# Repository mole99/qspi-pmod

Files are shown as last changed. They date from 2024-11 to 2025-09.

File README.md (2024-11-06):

# QSPI Pmod

A QSPI Pmod board designed in KiCad with one SPI Flash and two PSRAMs.

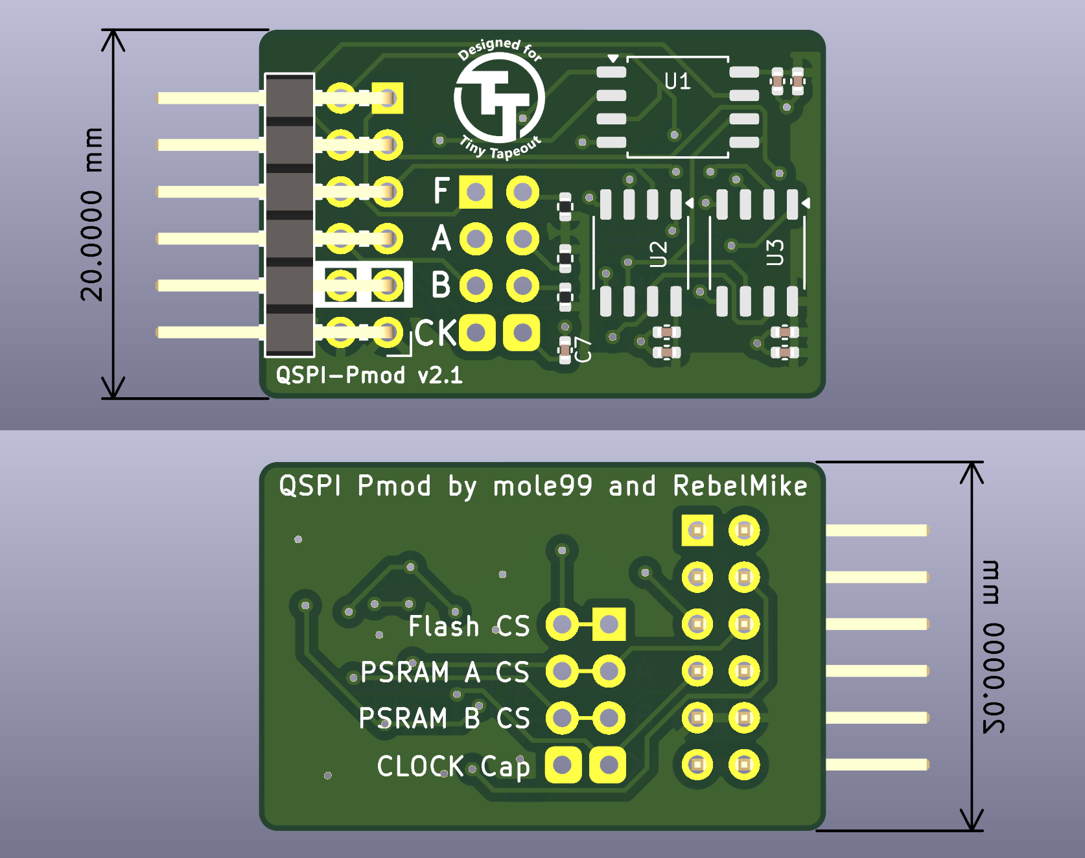
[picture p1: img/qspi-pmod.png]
PCB


# Pinout

| Pmod  | TinyTapeout | Function | Note |
|---|---|---|---|
| PMOD1 | uio[0] | CS0 (Flash) | Cut trace to disable (see below) |
| PMOD2 | uio[1] | SD0/MOSI | |
| PMOD3 | uio[2] | SD1/MISO | |
| PMOD4 | uio[3] | SCK | Short `CK` ("CLOCK cap") pin pair for delay by 22pF cap |
| PMOD5 | uio[4] | SD2 | |
| PMOD6 | uio[5] | SD3 | |
| PMOD7 | uio[6] | CS1 (RAM A) | Cut trace to disable (see below) |
| PMOD8 | uio[7] | CS2 (RAM B) | Cut trace to disable (see below) |

> [!NOTE]
> On the bottom side of the PCB, you can cut the traces for any of the 3 CS pins to disable its respective memory IC. When cut, a 1k resistor pulls up the chip's `/CS` to disable it. In this case, the respective pin could be used (via header thru-hole on the other side of the cut) as either an input or output.

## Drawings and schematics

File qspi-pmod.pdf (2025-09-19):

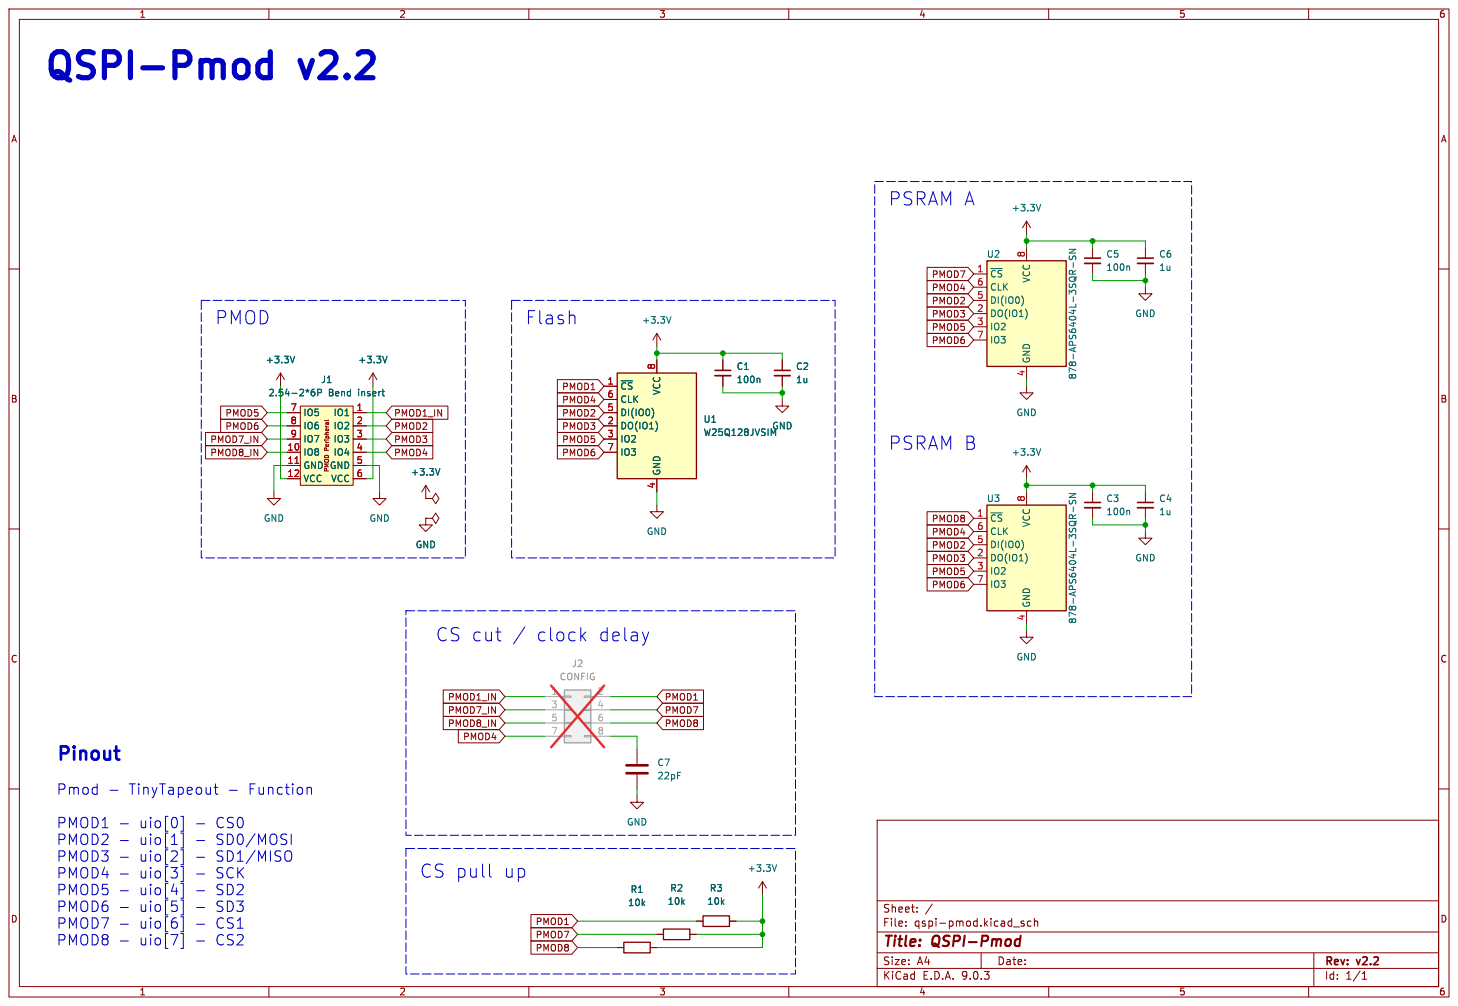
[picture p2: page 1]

CS cut / clock delay

File: qspi-pmod.kicad_sch Sheet: / R3

Id: 1/1 Title: QSPI-Pmod

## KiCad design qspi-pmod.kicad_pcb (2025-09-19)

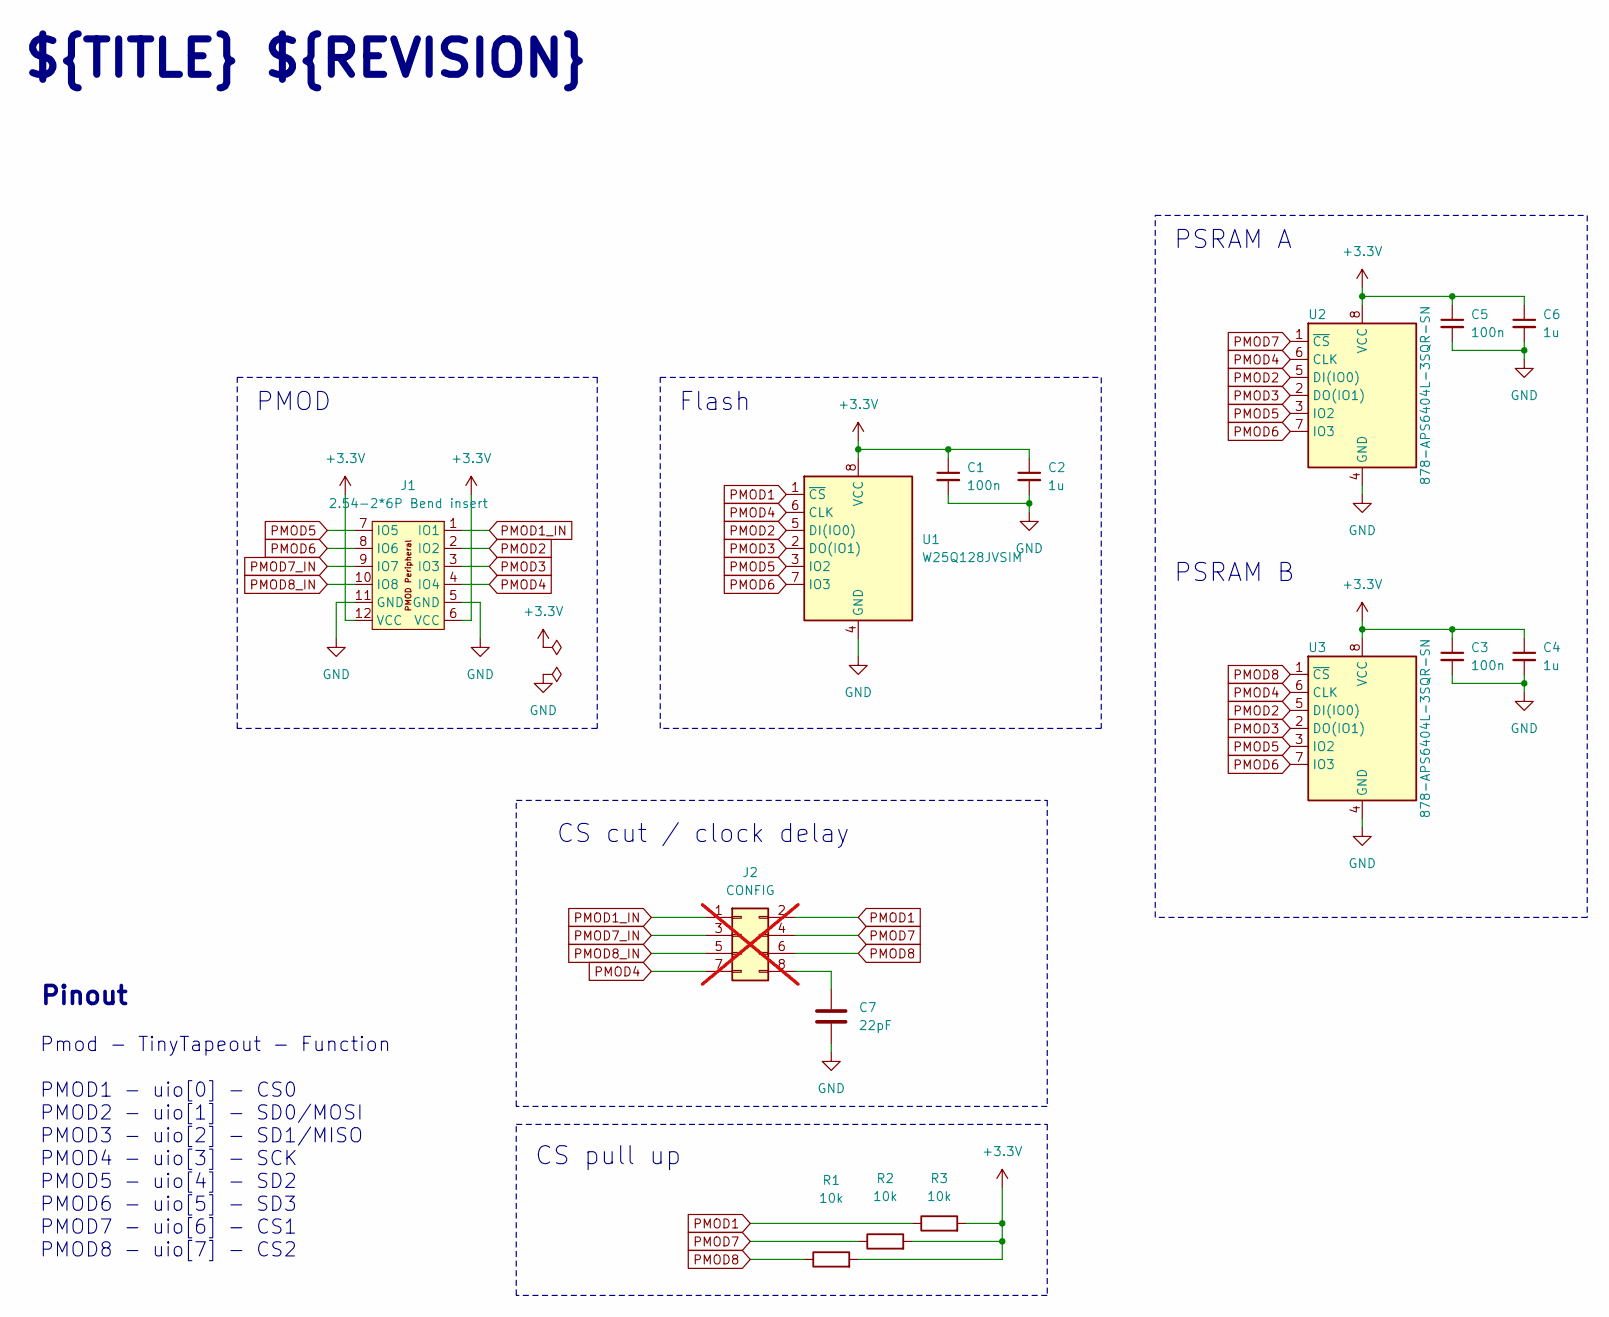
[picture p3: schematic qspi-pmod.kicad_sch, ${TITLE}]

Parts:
C1, C3, C5: 100n; C_0402_1005Metric; MPN 0402YC104KAT2A
C2, C4, C6: 1u; C_0402_1005Metric; MPN C0402C105M9PAC
C7: 22pF; C_0402_1005Metric; MPN 0402CG220J500NT
J1: 2.54-2*6P Bend insert; PinHeader_2x06_P2.54mm_PMODPeriph2B; MPN 2.54-2*6P; LCSC Part C60565
J2: CONFIG; PinHeader_2x04_P2.54mm_Vertical; not fitted
R1, R2, R3: 10k; R_0402_1005Metric; MPN 0402WGF1002TCE
U1: W25Q128JVSIM; SOIC-8_5.23x5.23mm_P1.27mm; MPN W25Q128JVSIM
U2, U3: 878-APS6404L-3SQR-SN; SOP-8_3.9x4.9mm_P1.27mm; MPN APS6404L-3SQR-SN

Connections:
+3.3V: C1.1, C2.1, C3.1, C4.1, C5.1, C6.1, J1.6 (VCC), J1.12 (VCC), R1.2, R2.2, R3.2, U1.8 (VCC), U2.8 (VCC), U3.8 (VCC)
GND: C1.2, C2.2, C3.2, C4.2, C5.2, C6.2, C7.1, J1.5 (GND), J1.11 (GND), U1.4 (GND), U2.4 (GND), U3.4 (GND)
unnamed: C7.2, J2.8
PMOD1: J2.2, R3.1, U1.1 (~CS)
PMOD1_IN: J1.1 (IO1), J2.1
PMOD2: J1.2 (IO2), U1.5 (DI(IO0)), U2.5 (DI(IO0)), U3.5 (DI(IO0))
PMOD3: J1.3 (IO3), U1.2 (DO(IO1)), U2.2 (DO(IO1)), U3.2 (DO(IO1))
PMOD4: J1.4 (IO4), J2.7, U1.6 (CLK), U2.6 (CLK), U3.6 (CLK)
PMOD5: J1.7 (IO5), U1.3 (IO2), U2.3 (IO2), U3.3 (IO2)
PMOD6: J1.8 (IO6), U1.7 (IO3), U2.7 (IO3), U3.7 (IO3)
PMOD7: J2.4, R2.1, U2.1 (~CS)
PMOD7_IN: J1.9 (IO7), J2.3
PMOD8: J2.6, R1.1, U3.1 (~CS)
PMOD8_IN: J1.10 (IO8), J2.5

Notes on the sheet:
CS cut / clock delay
PMOD
Flash
PSRAM B
CS pull up
${TITLE} ${REVISION}
PSRAM A
Pmod - TinyTapeout - Function PMOD1 - uio[0] - CS0 PMOD2 - uio[1] - SD0/MOSI PMOD3 - uio[2] - SD1/MISO PMOD4 - uio[3] - SCK PMOD5 - uio[4] - SD2 PMOD6 - uio[5] - SD3 PMOD7 - uio[6] - CS1 PMOD8 - uio[7] - CS2
Pinout

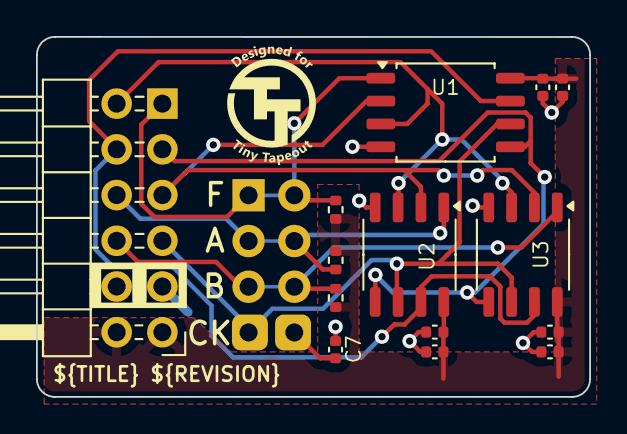
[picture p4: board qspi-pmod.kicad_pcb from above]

Board: 2 copper layers, 30.7 x 20.0 mm, 15 parts (0 on the bottom side), 14 nets.

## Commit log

2023-11-11 Push schematic and board
    [qspi-pmod.kicad_pcb, qspi-pmod.kicad_sch]
2023-11-11 Add 3D models
    [qspi-pmod.kicad_pcb]
2023-12-09 Finish routing
    [qspi-pmod.kicad_pcb, qspi-pmod.kicad_sch]
2024-01-25 Apply minimum copper to edge clearance
    [qspi-pmod.kicad_pcb]
2024-08-07 Add optional CLK cap and CS disconnects
    [qspi-pmod.kicad_pcb, qspi-pmod.kicad_sch]
2024-08-08 A few small tweaks
    [qspi-pmod.kicad_pcb]
2024-08-08 Part numbers
    [qspi-pmod.kicad_pcb]
2024-08-09 Use text variables
    [qspi-pmod.kicad_pcb]
2024-08-09 Change cap to 22pF
    [qspi-pmod.kicad_pcb, qspi-pmod.kicad_sch]
2024-08-12 BOM updates
    [qspi-pmod.kicad_pcb, qspi-pmod.kicad_sch]
2024-11-01 Clarify CS pin functions
2024-11-05 Update README re CS/cap traces and v2.1 board pic top/bottom
2025-09-19 Make pull ups 10k
    [qspi-pmod.kicad_pcb, qspi-pmod.kicad_sch]
